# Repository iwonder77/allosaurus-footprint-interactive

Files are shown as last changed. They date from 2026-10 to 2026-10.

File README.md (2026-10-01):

# Allosaurus Footprint Stomp Pad Interactive

Three-channel, optically-isolated 24 V input board plus ESP32 show controller that turns industrial safety mats ("stomp pads") into clean, debounced triggers for synchronized video and LED strip output at the Need for Speed exhibit in Thanksgiving Point's Museum of Ancient Life. A visitor stomps a footprint mat, and the matching dinosaur's clip plays with an accompanying light strip animation around that Allosaurus' femur bone cast.

---

## At a Glance

| | |
| --- | --- |
| **Input domain** | 24 V DC current loop, one per mat (field wiring, up to ~10 ft) |
| **Logic domain** | 3.3 V, shared with the controller (no level shifting needed) |
| **Channels / mats** | 3 - `hatchling`, `juvenile`, `adult` (one per footprint mat) |
| **Input per channel** | ASOSafety safety mat (normally-open, passive dry contact) |
| **Isolation** | onsemi **H11L1M** optocoupler - one per channel |
| **Controller** | **ESP32-DevKitC** (`fqbn: esp32:esp32:esp32`) firmware sketch in `esp32/` |
| **Input logic** | Mat pressed → `Vo` LOW (**active-low**, external pull-up idles HIGH) |
| **Output banks** | Media (BrightSign) + LED Light Strip (controlled by QuinLED), both **active-low** 200 ms pulses |
| **Show rule** | First stomp wins; all mats locked out until that clip finishes |
| **PCB** | `2-layer, JLCPCB fab + assembly` |
| **Status** | PCB version June 2026 designed (see `ERRATA.md`) · firmware complete |

---

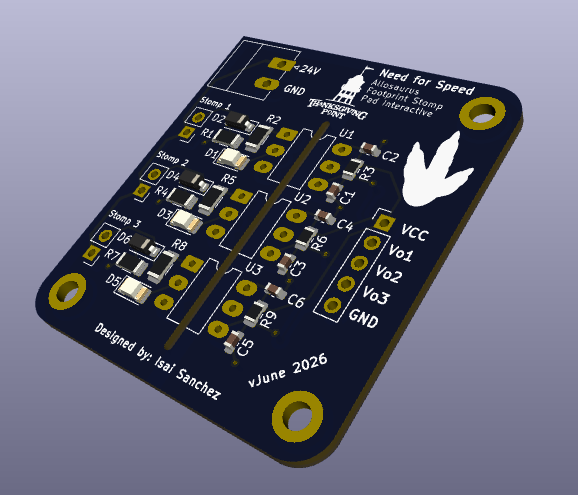
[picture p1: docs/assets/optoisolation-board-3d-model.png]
3D PCB Model


---

## Overview

The Allosaurus Footprint interactive lets visitors stomp on floor-mounted pads to trigger a short video, audio, and light response - a video clip on a BrightSign player and an LED-strip animation on a QuinLED driver - fired in sync from a single step. Each pad is an **industrial normally-open safety mat used here purely as a rugged foot switch** in order to run unattended 24/7 in an abusive museum exhibit environment.

The obvious approach is to wire each mat's dry contact straight into a GPIO with the internal pull-up and debounce in firmware. That may work on a bench, but is not the bullet proof solution on the floor for the following reasons:

- The mats sit **up to ~10 ft** from the controller.
- The exhibit must run **24/7, unattended, for years**, with **hundreds of activations a day** and cannot experience any brown-out or mat trigger failures.
- Hundreds of visitors means hundreds of potential **ESD events** onto the mat wiring.
- Industrial-rated mats need a "wetting" current to ensure reliable long-term operation of the dry contacts (part of the reason manufacturers specify connecting to a 24V system)

A bare high-impedance GPIO sense on a 10 ft run is an antenna prone to noise pickup and false triggers. The optoisolation board I designed was a cheap bulletproof add-on to solves both problems at the input stage, so the controller only ever sees a clean, isolated, logic-level edge - then the firmware does debounce, fault detection, and show sequencing on top.

---

# Hardware

## Hardware Design Requirements

The input board needed to:

- Convert a passive N.O. mat closure into a reliable 3.3 V logic trigger.
- Provide **galvanic isolation** between the 24 V field wiring and the 3.3 V logic, so ground offsets and transients on the mat side cannot reach the MCU.
- Resist false triggers from noise coupled onto the long mat cabling.
- Give maintenance staff a **visible per-channel indicator** to confirm at a glance that a mat is being pressed and its sense path is driven.
- Be manufacturable at JLCPCB (fab + assembly) with clean, auditable part placement and silkscreen labels.
- Run for years with essentially zero maintenance.

These led to a **24 V current loop driving an optocoupler per channel**: the current loop resists noise, adds a bit of "wetting" current, and the optocoupler provides isolation plus a clean Schmitt-trigger output edge for the show controller.

## Main Hardware Components

- onsemi **H11L1M** optocoupler - integrated **Schmitt-trigger, open-collector, logic-compatible** output
- **1N4148W** small-signal diode - reverse-polarity protection across the optocoupler input
- Visible indicator LED (green SMD) - per channel, on the input side
- Current-limiting resistors, pull-up resistors, decoupling/filter capacitors (see **Design Notes**)

The full BOM lives in `manufacturing/`.

## Full Schematic

Full schematic

## Main Hardware Architecture

The three channels are identical.

**Input side (referenced to `GND1`, the 24 V ground):**

```
+24V ── mat (N.O.) ── R_series ── [indicator LED] ── H11L1M IR LED ── GND1
                 └── D2 (1N4148W) across the LED string, reverse protection
```

While someone stands on the mat the contact closes and current flows, driving the H11L1M input IR LED and lighting the visible indicator - so the indicator doubles as direct confirmation the sense LED is driven.

> **Note:** rev 1 places the indicator LED _in series_ with the IR LED. This works but is being revised to a parallel branch - see **Hardware Revisions** and `ERRATA.md`.

**Output side (referenced to `GND2`, the 3.3 V ground):**

```
+3V3 ── R_pullup (2.2 kΩ) ──┬── Vo (H11L1M open-collector) ── ESP32 GPIO
                            └── C1 (0.1 µF) noise filter to GND2
+3V3 ── C2 (0.1 µF) decoupling, close to the H11L1M VCC pin ── GND2
```

The output is **active-low on a press**: pressed → IR LED on → output transistor on → `Vo` LOW. Idle → `Vo` pulled HIGH by the 2.2 kΩ. The output-side `VCC` shares the 3.3 V rail with the MCU so HIGH can never exceed the MCU input rail.

| Mat state | IR LED | `Vo` node | GPIO reads | Indicator LED |
| --- | --- | --- | --- | --- |
| Idle (open) | off | HIGH (~3.07 V) | HIGH | off |
| Pressed (closed) | on | LOW (≤ 0.4 V)  | LOW | lit |

## Design Notes

### Why a 24 V current loop instead of a bare GPIO

**Current loop, not voltage sense.** Pushing real current (target ~9–10 mA) through the H11L1M input LED is a low-impedance path; noise must overcome actual current to look like a valid change. Far harder to corrupt than a voltage on a high-impedance node over 10 ft.

**Wetting current (bonus).** Meaningful current through the dry mat contacts keeps a **wetting current** flowing, which helps those contacts resist any oxide film that makes aging switches flaky. This sets a _floor_ on the sense-branch current independent of the opto's switching threshold.

### Optocoupler output logic and levels

The H11L1M's integrated Schmitt trigger gives clean, bounce-free edges. Verified against the controller's input thresholds (ESP32 input thresholds are ratios of VDD):

| Parameter | Value | Source |
| --- | --- | --- |
| `V_IH(min)` ≈ 0.75·VDD | ~2.48 V | ESP32 datasheet |
| `V_IL(max)` ≈ 0.25·VDD | ~0.83 V | ESP32 datasheet |
| H11L1M `V_OL` | ≤ 0.4 V | datasheet (sinks 16 mA at 0.4 V max) |
| H11L1M output-off leakage `I_OH` | 100 µA  | datasheet |
| H11L1M `V_CC` range (min **3.0 V**) | 3–16 V  | datasheet |

With a **2.2 kΩ pull-up**: HIGH ≈ 3.3 − (~105 µA)(2.2 kΩ) ≈ **3.07 V** (~0.6 V over `V_IH`); LOW ≤ **0.4 V** (~0.4 V under `V_IL`); pressed-state sink ≈ 1.3 mA (far below 16 mA). The binding constraint is the HIGH side — the 100 µA leakage droops it — so the pull-up is kept small-ish. `C1` = 0.1 µF with the 2.2 kΩ gives RC ≈ **220 µs**: a **glitch filter, not a debouncer**. Mat bounce runs for milliseconds, so firmware debounce is still mandatory (and the firmware does far more than that - see below).

### Reverse-polarity protection

The 1N4148W spans the forward LED string, reverse-biased in normal use, conducting only on a reversed-polarity miswire. Confirm its orientation (cathode toward +24 V in normal operation). A single series Schottky on the 24 V input is the tidier belt-and-suspenders option if full reverse immunity is ever wanted.

## Hardware Revisions

Two changes are planned for the next board spin. **version June 2026 is functional as-is** - these are improvements, not blockers. Full detail, rationale, and selection guidance live in **[`ERRATA.md`](./ERRATA.md)** next to the rev-1 schematic/PCB files.

- **ERRATA-1: Indicator LED should be parallel, not series.** Version June 2026 shares one loop current between the IR LED and the indicator. Moving the indicator to its own parallel branch (each LED with its own resistor) lets each current be sized independently and stops an open-failed indicator from killing the sense path. **Recompute the opto current when you do**.
- **ERRATA-2: Add a TVS at each mat connector.** Given public foot traffic (ESD) over ~10 ft of exposed cable, 24/7 for years, a unidirectional TVS at each input protects the front-end. (It does _not_ protect the ESP32 - the opto already does that.) Recommended, not required.

## PCB & Manufacturing

**Isolation strategy (the whole point).** `GND1` (24 V) and `GND2` (3.3 V) are separate nets that **never** connect on the board - the only crossing is the opto's light barrier. Two separate bottom-layer copper pours with a ~3 mm gap, the barrier line running through each optocoupler, all three optos oriented identically.

**Mounting holes - verified safe.** The four corner holes carry **no copper** and take plastic standoffs for a custom 3D-printed mount, so hardware can't bridge `GND1` to `GND2`.

**Net classes**

| Class | Track width | Nets |
| --- | --- | --- |
| `Input_24V`  | 0.5 mm | `+24V`, `GND1` |
| `Output_3V3` | 0.3 mm | `+3V3`, `GND2`, `Vo` |

Both share via 0.6 mm / hole 0.3 mm (0.15 mm annular) and 0.3 mm clearance.

---

# Firmware

`esp32/` — a single non-blocking sketch that reads the three mats, validates each stomp, and fires the matching media + light triggers. No RTOS tasks, no delays; `loop()` runs the whole thing and feeds a hardware watchdog every pass.

## Pinout — `esp32/`

All constants live in `src/Config.h`. Index `i` ties together input `[i]`, media `[i]`, and light `[i]` (mat 1 = hatchling, 2 = juvenile, 3 = adult).

| GPIO | Direction | Connects to | Constant |
| --- | --- | --- | --- |
| 13 | Input (active-low)  | `Vo1` - hatchling opto output | `MAT_INPUT_PINS[0]` |
| 14 | Input (active-low)  | `Vo2` - juvenile opto output | `MAT_INPUT_PINS[1]` |
| 15 | Input (active-low)  | `Vo3` - adult opto output | `MAT_INPUT_PINS[2]` |
| 21 | Output (active-low) | BrightSign trigger - hatchling clip | `MEDIA_TRIGGER_PINS[0]` |
| 22 | Output (active-low) | BrightSign trigger - juvenile clip  | `MEDIA_TRIGGER_PINS[1]` |
| 23 | Output (active-low) | BrightSign trigger - adult clip | `MEDIA_TRIGGER_PINS[2]` |
| 16 | Output (active-low) | QuinLED trigger - hatchling strip | `LIGHT_TRIGGER_PINS[0]` |
| 17 | Output (active-low) | QuinLED trigger - juvenile strip | `LIGHT_TRIGGER_PINS[1]` |
| 18 | Output (active-low) | QuinLED trigger - adult strip | `LIGHT_TRIGGER_PINS[2]` |
| 25/26/27 | _reserved_ | former audio bank (WAV Trigger) | - (do not reuse) |

## Behavior

**Debounce / validation (per mat).** Three independent timing knobs in `Config.h`, each rejecting a different failure mode — deliberately not collapsed into one value:

| Knob | Default | Rejects |
| --- | --- | --- |
| `MAT_DEBOUNCE_MS` | 10 ms | fast edge chatter - line must be stable this long |
| `MAT_MIN_ON_MS` | 30 ms | short spikes - press must dwell this long to count (≥ debounce); also the event latency |
| `MAT_REARM_MS` | 80 ms | bouncy releases - line must read clear this long to re-arm |

**One video at a time (global lockout).** The first validated stomp wins: its clip is triggered and **every** mat input is ignored until that clip finishes, so a video always plays start-to-finish and is never cut off or re-triggered. Lockout = `VIDEO_LENGTH_MS[i]` (13 / 17 / 22 s) + `RETRIGGER_HEADROOM_MS` (1 s) → ~14 / 18 / 23 s. A stomp arriving during a lockout is **discarded**, not queued. This is a different mechanism from `MAT_REARM_MS` (a low-level per-mat cooldown).

**Fail-closed detection.** If a mat reads active continuously for `MAT_STUCK_MS` (10 s - far longer than any real stomp: a welded contact, a stuck mat, or a shorted line), that mat is flagged **faulted**: it stops emitting events and its outputs are forced idle so a stuck input can't leave a device asserted. It auto-recovers after the line reads clear for `MAT_FAULT_RECOVER_MS` (500 ms), re-arming through the boot-safe path.

**Boot-safe.** Each detector starts in `WaitForRelease`, so a mat already held down at power-on never produces a spurious event - it arms only after a confirmed clean release.

**Watchdog.** `loop()` is fully non-blocking and feeds the task watchdog (TWDT) every pass. If anything ever wedges the main task past `WDT_TIMEOUT_MS` (5 s), the watchdog panics and resets the board - the exhibit self-recovers instead of hanging.

## Architecture

The `.ino` handles bring-up (pin setup, watchdog subscribe) and the per-mat loop; the real press logic lives in `src/`.

- **`MatInput`**: a non-blocking, debounced press detector for one active-low opto input, owning only its own state machine (no dependency on Serial or the outputs). `update()` advances it, `eventFired()` latches true exactly once per validated stomp (reading clears it), `pressed()` / `faulted()` / `rawActive()` expose state. The FSM: `WaitForRelease → Armed → PressDebounce → PressConfirm → Held`, with `Faulted` entered from anywhere on a stuck line. Fault and min-on timing are measured against `millis()` marks, so nothing blocks.
- **Main sketch (`esp32.ino`)**: owns one `MatInput` per mat and two output banks (`BANK_MEDIA`, `BANK_LIGHT`) in an index-aligned table, so `triggerMat(i)` fires both of mat `i`'s lines at once and `serviceOutputs()` returns each to idle after the pulse width — non-blocking, so mat scanning never stalls behind an in-flight pulse. It owns the global lockout, logs faults/recoveries once on their edge, and forces a faulted mat's outputs idle. The lockout comparison is rollover-safe (`(int32_t)(now - lockoutUntil) >= 0`).
- **`Config.h`**: single source of truth for pins, polarity, and all timing. `constexpr` throughout (compile-time, zero RAM). Everything you'd tune on the bench lives here so the logic modules stay untouched.

## Deployment & Bring-up

### Flashing

Platform is set in `sketch.yaml` (`esp32:esp32:esp32`). `default_port` is committed as `/dev/cu.usbserial-0001` - **change it to your machine's serial port**, or pass `-p <port>` on upload. A plain `arduino-cli compile` / `upload` builds and flashes the sketch.

### Tuning on the real mat

Leave `SERIAL_LOG_EVENTS = true` and watch the serial console at **115200**. Then:

- **Double-triggers on one stomp** → increase `MAT_DEBOUNCE_MS` (and/or `MAT_REARM_MS`).
- **Missed / dropped stomps** → decrease `MAT_MIN_ON_MS` (keep it ≥ `MAT_DEBOUNCE_MS`).
- Set `VIDEO_LENGTH_MS[]` to the **real** clip durations per mat - these drive the lockout, so a value shorter than the clip will let the exhibit re-arm mid-video.

### What working looks like

| Event | Serial line |
| --- | --- |
| Boot | `Allosaurus Footprint Interactive - ready` |
| Valid stomp | `Mat N triggered (input GPIO .. -> media .. / light ..); ignoring all mats for .. ms` |
| Stuck mat / short | `FAULT: Mat N stuck active (input GPIO ..) - check for a failed-closed mat/short` |
| Fault clears | `RECOVERED: Mat N back to normal (input GPIO ..)` |

### When something is wrong

| Symptom | Likely cause | Check |
| --- | --- | --- |
| A mat never triggers | Input wiring / opto / that mat | Does the on-board indicator LED light on press? Is `Vo` reaching the right GPIO? |
| A stomp fires media but not lights (or vice-versa) | One output bank's wire | That mat's `MEDIA`/`LIGHT` GPIO to the device input, plus common ground |
| Downstream device never reacts to a pulse | Polarity / reference mismatch | Device must trigger on an **active-LOW** pulse and share ground; input must be 3.3 V |
| `FAULT: Mat N stuck active` on repeat | Welded contact, stuck mat, or shorted run | Inspect that mat and its cable; fault clears itself once the line reads clear |
| Exhibit ignores stomps for ~15–25 s | **Not a fault** — global lockout | A clip is playing; by design all mats are ignored until it ends |
| Board reboots every few seconds | Watchdog fired — `loop()` stalled | Something is blocking the main task; check recent changes / peripherals |

### Quirks worth knowing

- **Simultaneous stomps: first wins.** If two mats are hit close together, only the first registers; the rest are ignored (not queued) until the clip finishes. Intended - one video at a time.
- **A stomp during a video does nothing.** Discarded, not buffered, so the exhibit never "fires late" when the lockout ends.
- **Audio is not wired.** An audio bank (SparkFun + Robertsonics WAV Trigger) was prototyped and removed; GPIO 25/26/27 are reserved. To restore it, re-add `AUDIO_TRIGGER_PINS[] = {25, 26, 27}`, its `static_assert`, and a `BANK_AUDIO` entry in `OUTPUT_BANK_PINS`.

---

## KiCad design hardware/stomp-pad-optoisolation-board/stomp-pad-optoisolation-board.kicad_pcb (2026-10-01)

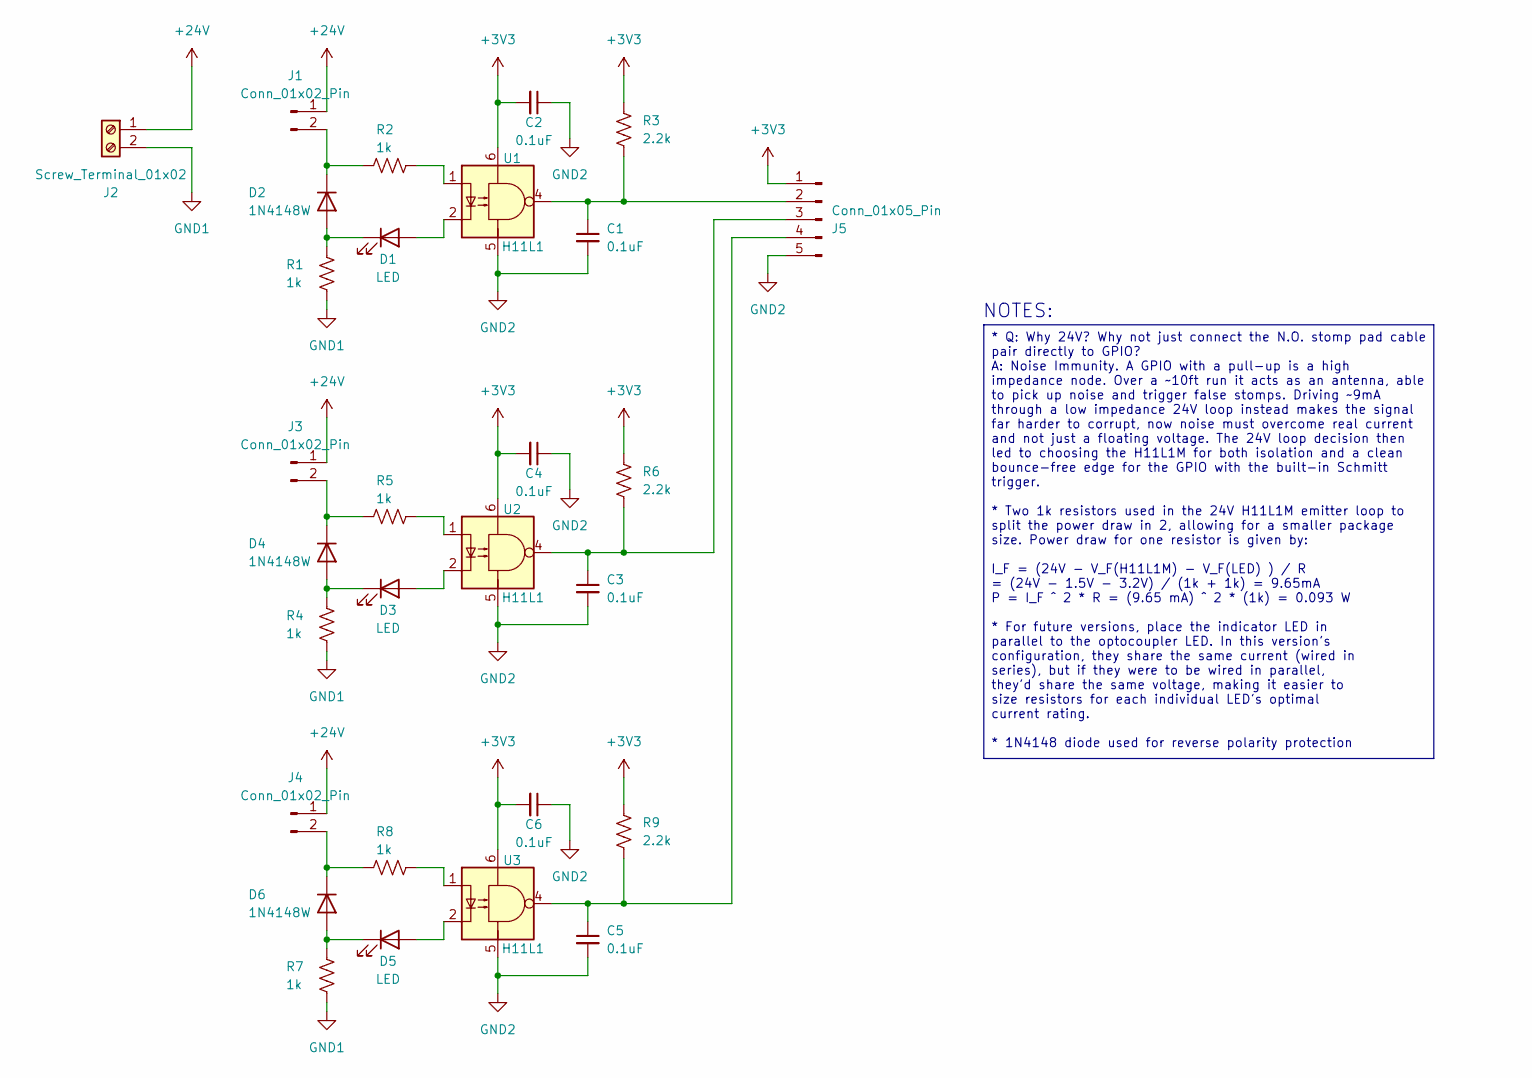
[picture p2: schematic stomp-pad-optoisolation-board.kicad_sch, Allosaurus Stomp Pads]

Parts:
C1, C2, C3, C4, C5, C6: 0.1uF; C_0603_1608Metric
D1, D3, D5: LED; LED_1206_3216Metric
D2, D4, D6: 1N4148W; D_SOD-123
J1, J3, J4: Conn_01x02_Pin; PinHeader_1x02_P2.54mm_Vertical
J2: Screw_Terminal_01x02; PhoenixContact_MC_1,5_2-G-3.5_1x02_P3.50mm_Horizontal
J5: Conn_01x05_Pin; PinHeader_1x05_P2.54mm_Vertical
R1, R2, R4, R5, R7, R8: 1k; R_1206_3216Metric
R3, R6, R9: 2.2k; R_0805_2012Metric
U1, U2, U3: H11L1; DIP-6_W7.62mm_LongPads

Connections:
+3V3: C2.2, C4.2, C6.2, J5.1, R3.1, R6.1, R9.1, U1.6, U2.6, U3.6
+24V: J1.1, J2.1, J3.1, J4.1
GND1: J2.2, R1.1, R4.1, R7.1
GND2: C1.2, C2.1, C3.2, C4.1, C5.2, C6.1, J5.5, U1.5, U2.5, U3.5
unnamed: D1.2 (A), U1.2
unnamed: D1.1 (K), D2.2 (A), R1.2
unnamed: D2.1 (K), J1.2, R2.1
unnamed: D3.2 (A), U2.2
unnamed: D3.1 (K), D4.2 (A), R4.2
unnamed: D4.1 (K), J3.2, R5.1
unnamed: D5.2 (A), U3.2
unnamed: D5.1 (K), D6.2 (A), R7.2
unnamed: D6.1 (K), J4.2, R8.1
unnamed: C1.1, J5.2, R3.2, U1.4
unnamed: C3.1, J5.3, R6.2, U2.4
unnamed: C5.1, J5.4, R9.2, U3.4
unnamed: R2.2, U1.1
unnamed: R5.2, U2.1
unnamed: R8.2, U3.1

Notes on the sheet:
NOTES:
* Q: Why 24V? Why not just connect the N.O. stomp pad cable pair directly to GPIO? A: Noise Immunity. A GPIO with a pull-up is a high impedance node. Over a ~10ft run it acts as an antenna, able to pick up noise and trigger false stomps. Driving ~9mA through a low impedance 24V loop instead makes t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

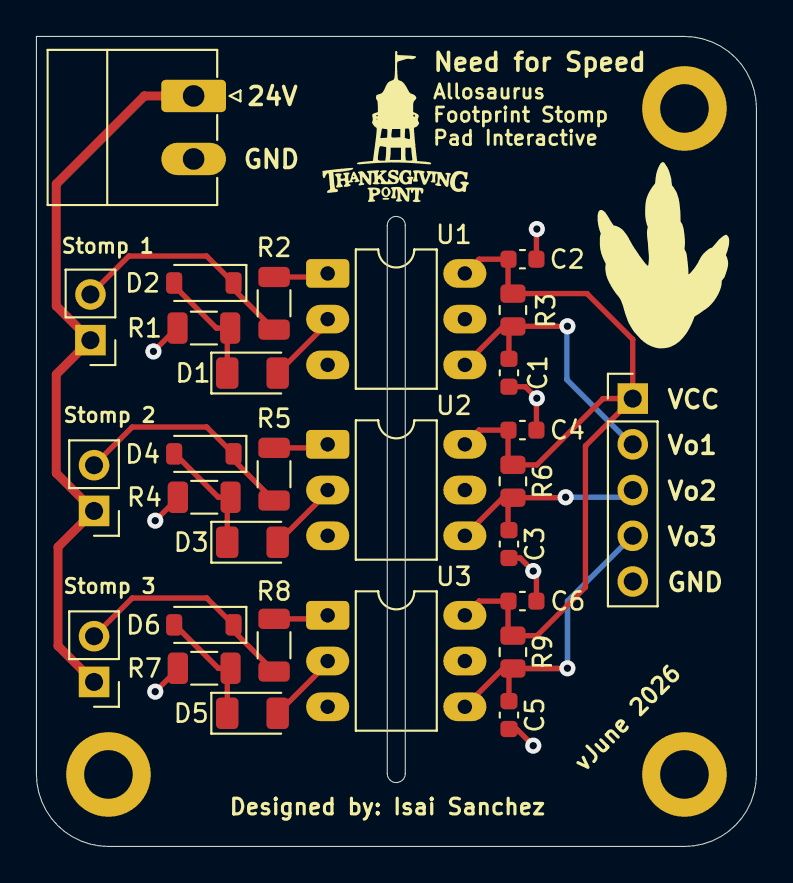
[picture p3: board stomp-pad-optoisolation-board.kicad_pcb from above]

Board: 2 copper layers, 40.0 x 45.0 mm, 29 parts (0 on the bottom side), 19 nets.

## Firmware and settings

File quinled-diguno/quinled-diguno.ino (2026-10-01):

/**
 * Allosaurus Footprint Interactive — LED strip controller
 * File: quinled-diguno.ino
 * Board: QuinLED Dig-Uno (ESP32-based; LED outputs are level-shifted to 5V)
 * Strip: WS2815 addressable, 152 pixels
 *
 * Behaviour:
 *   - IDLE: the whole strip holds a constant warm white / amber glow.
 *   - On a stomp (GPIO15 pulled LOW by the optocoupler mat-trigger board) a fast
 *     red "snake" wipes down the strip: a leading pixel advances and every pixel
 *     it passes stays red, overtaking the amber glow. When the head reaches the
 *     final pixel the strip holds full red for FULL_RED_HOLD_MS (ignoring any
 *     further stomps), then cross-fades smoothly back to the amber idle glow.
 *
 * The GPIO15 input is debounced with the same active-low state machine used by
 * the esp32 mat sketch (debounce window + minimum on-time + re-arm cooldown,
 * plus boot-safety), so contact/optocoupler chatter can't double-fire.
 *
 * PER-BOARD BUILD: each QuinLED board accompanies one mat's video, and its
 * animation cycle equals that video's length, selected at COMPILE TIME with
 * -DBOARD_ID=n (see the "Per-board video length" section below).
 */

#include <FastLED.h>

// ===================== LED strip ==========================================
constexpr uint16_t NUM_LEDS = 152;
constexpr uint8_t LED_DATA_PIN = 3;  // QuinLED Dig-Uno LED data output
#define LED_TYPE WS2815
#define COLOR_ORDER GRB
constexpr uint8_t BRIGHTNESS_PCT = 75;  // master brightness, percent

// Idle glow and snake colors. IDLE_COLOR is a warm, slightly-amber white; tune
// the green/blue channels down for more amber, up for cooler white.
const CRGB IDLE_COLOR = CRGB(255, 120, 40);
const CRGB SNAKE_COLOR = CRGB::Red;

// ===================== Snake animation ====================================

constexpr float SNAKE_SPEED_PPS = 100.0f;  // leading-pixel speed, pixels/sec (higher = faster)
constexpr uint8_t TARGET_FPS = 120;        // render cap

// ===================== Per-board video length (compile-time) =============
/*
 * This board's animation runs for exactly one video length: the snake wipe, the
 * full-red hold, and the closing fade back to idle. The hold is whatever time
 * is left after the wipe and fade, so wipe + hold + fade always sums to
 * TOTAL_CYCLE_MS (see the derivation below) — raise SNAKE_SPEED_PPS and the hold
 * grows, lower it and the hold shrinks. Stomps on MAT_INPUT_PIN are ignored for
 * the whole cycle.
 *
 * Each QuinLED board accompanies one mat's video, so TOTAL_CYCLE_MS is that
 * video's length, chosen at COMPILE TIME. All three lengths live in the array
 * below (index-matched to the mats, mirroring VIDEO_LENGTH_MS[] in the esp32
 * sketch); BOARD_ID picks which one THIS board uses:
 *
 *   arduino-cli compile --build-property \
 *     compiler.cpp.extra_flags=-DBOARD_ID=2 --fqbn esp32:esp32:esp32 quinled-diguno
 *
 * A plain build with no -DBOARD_ID defaults to mat 1, so it still compiles/runs.
 */
#ifndef BOARD_ID
#define BOARD_ID 3
#endif

constexpr uint32_t VIDEO_LENGTHS_MS[] = {
  12000,  // hatchling footprint mat clip length
  16000,  // juvenile footprint mat clip length
  21000,  // adult footprint mat clip length
};
static_assert(BOARD_ID >= 1 && BOARD_ID <= (int)(sizeof(VIDEO_LENGTHS_MS) / sizeof(VIDEO_LENGTHS_MS[0])),
              "BOARD_ID must be 1..3; set it with -DBOARD_ID=n at compile time");

// This board's animation cycle == its video length.
constexpr uint32_t TOTAL_CYCLE_MS = VIDEO_LENGTHS_MS[BOARD_ID - 1];

// Smooth cross-fade from full red back to the amber idle glow at the end of the
// cycle. This is carved out of TOTAL_CYCLE_MS, not added on top.
constexpr uint32_t FADE_TO_IDLE_MS = 1000;

// Nominal time for the head to travel the strip (head goes from pixel 0 to
// NUM_LEDS-1 at SNAKE_SPEED_PPS); the rest of the budget is the full-red hold.
constexpr uint32_t SNAKE_WIPE_MS =
  (uint32_t)((NUM_LEDS - 1) / SNAKE_SPEED_PPS * 1000.0f);
static_assert(SNAKE_WIPE_MS + FADE_TO_IDLE_MS <= TOTAL_CYCLE_MS,
              "Snake wipe + fade exceed TOTAL_CYCLE_MS; raise the total or speed");
constexpr uint32_t FULL_RED_HOLD_MS =
  TOTAL_CYCLE_MS - SNAKE_WIPE_MS - FADE_TO_IDLE_MS;

constexpr uint16_t FRAME_INTERVAL_MS = 1000 / TARGET_FPS;

// ===================== Mat trigger input (optocoupler) ====================
// GPIO15 idles HIGH (external pull-up on the opto board) and is pulled LOW when
// the mat is stomped. GPIO15 is an ESP32 strapping pin that must be HIGH at
// boot — idle-HIGH satisfies that, so this wiring is boot-safe.
#define MAT_INPUT_PIN 32
constexpr bool MAT_ACTIVE_LOW = true;
constexpr bool MAT_USE_INTERNAL_PULLUP = true;  // `false` if external pull-up present

// Three independent debounce knobs (see the esp32 sketch's Config.h for the
// rationale of each). MAT_MIN_ON_MS must be >= MAT_DEBOUNCE_MS.
constexpr uint16_t MAT_DEBOUNCE_MS = 10;  // edge stability window
constexpr uint16_t MAT_MIN_ON_MS = 30;    // min dwell to count
constexpr uint16_t MAT_REARM_MS = 1000;   // min off-time before re-arming

/*
 * MatTrigger — non-blocking, debounced press detector for one active-low input.
 * Fires eventFired() exactly once per validated stomp. begin() starts in
 * WaitForRelease so a mat held at power-on never produces a spurious trigger.
 */
class MatTrigger {
public:
  void begin(uint8_t pin) {
    pin_ = pin;
    pinMode(pin_, MAT_USE_INTERNAL_PULLUP ? INPUT_PULLUP : INPUT);
    state_ = WaitForRelease;
    event_ = false;
    t_mark_ = millis();
  }

  // Advance the state machine. Non-blocking; call every loop.
  void update() {
    const uint32_t now = millis();
    const bool active = rawActive();

    switch (state_) {
      case WaitForRelease:  // boot-safe entry + cooldown; needs continuous release
        if (active) {
          t_mark_ = now;
        } else if (now - t_mark_ >= MAT_REARM_MS) {
          state_ = Armed;
        }
        break;

      case Armed:
        if (active) {  // first active edge
          t_mark_ = now;
          state_ = PressDebounce;
        }
        break;

      case PressDebounce:
        if (!active) {
          state_ = Armed;  // dropped during debounce -> chatter
        } else if (now - t_mark_ >= MAT_DEBOUNCE_MS) {
          state_ = PressConfirm;
        }
        break;

      case PressConfirm:  // min-on measured from the first edge
        if (!active) {
          t_mark_ = now;
          state_ = WaitForRelease;  // released too soon -> too short
        } else if (now - t_mark_ >= MAT_MIN_ON_MS) {
          event_ = true;  // VALIDATED STOMP — latch the event
          state_ = Held;
        }
        break;

      case Held:
        if (!active) {
          t_mark_ = now;  // begin cooldown
          state_ = WaitForRelease;
        }
        break;
    }
  }

  // True exactly once per validated stomp; reading it clears the latch.
  bool eventFired() {
    if (event_) {
      event_ = false;
      return true;
    }
    return false;
  }

private:
  bool rawActive() const {
    const int level = digitalRead(pin_);
    return MAT_ACTIVE_LOW ? (level == LOW) : (level == HIGH);
  }

  enum State : uint8_t { WaitForRelease,
                         Armed,
                         PressDebounce,
                         PressConfirm,
                         Held };

  uint8_t pin_ = 0;
  State state_ = WaitForRelease;
  bool event_ = false;
  uint32_t t_mark_ = 0;
};

// ===================== Runtime state ======================================
CRGB leds[NUM_LEDS];
MatTrigger mat;

enum Mode : uint8_t { IDLE,
                      SNAKE,
                      SNAKE_HOLD,
                      FADE_TO_IDLE };
Mode mode = IDLE;

float snakeHead = 0.0f;    // leading-pixel position, fractional
uint32_t lastFrameMs = 0;  // last rendered frame timestamp
uint32_t holdStart = 0;    // full-red dwell start timestamp
uint32_t fadeStart = 0;    // fade-to-idle start timestamp

// Paint the whole strip with the amber idle glow.
void renderIdle() {
  fill_solid(leds, NUM_LEDS, IDLE_COLOR);
  FastLED.show();
}

// Begin the red snake wipe from the first pixel.
void startSnake(uint32_t now) {
  mode = SNAKE;
  snakeHead = 0.0f;
  lastFrameMs = now;
}

// Advance and draw one snake frame: pixels at/behind the head are red, pixels
// ahead of it keep the amber idle glow. Transitions to SNAKE_HOLD at the end.
void updateSnake(uint32_t now) {
  const uint32_t dtMs = now - lastFrameMs;
  if (dtMs < FRAME_INTERVAL_MS) return;
  lastFrameMs = now;

  snakeHead += SNAKE_SPEED_PPS * (dtMs / 1000.0f);

  int head = (int)snakeHead;
  bool reachedEnd = false;
  if (head >= NUM_LEDS - 1) {
    head = NUM_LEDS - 1;
    reachedEnd = true;
  }

  for (int i = 0; i < NUM_LEDS; ++i) {
    leds[i] = (i <= head) ? SNAKE_COLOR : IDLE_COLOR;
  }
  FastLED.show();

  if (reachedEnd) {
    mode = SNAKE_HOLD;
    holdStart = now;
  }
}

// Cross-fade the whole strip from full red back to the amber idle glow over
// FADE_TO_IDLE_MS, then settle into IDLE. The strip is uniform here, so one
// blended color fills every pixel.
void updateFade(uint32_t now) {
  const uint32_t dtMs = now - lastFrameMs;
  if (dtMs < FRAME_INTERVAL_MS) return;
  lastFrameMs = now;

  const uint32_t elapsed = now - fadeStart;
  if (elapsed >= FADE_TO_IDLE_MS) {
    mode = IDLE;
    renderIdle();
    return;
  }

  // 0 -> full red, 255 -> full idle color.
  const uint8_t amount = (uint8_t)(elapsed * 255UL / FADE_TO_IDLE_MS);
  fill_solid(leds, NUM_LEDS, blend(SNAKE_COLOR, IDLE_COLOR, amount));
  FastLED.show();
}

void setup() {
  FastLED.addLeds<LED_TYPE, LED_DATA_PIN, COLOR_ORDER>(leds, NUM_LEDS);
  FastLED.setBrightness((255 * BRIGHTNESS_PCT) / 100);

  mat.begin(MAT_INPUT_PIN);

  renderIdle();
}

void loop() {
  const uint32_t now = millis();

  mat.update();
  const bool stomped = mat.eventFired();

  switch (mode) {
    case IDLE:
      if (stomped) startSnake(now);  // stomps during animation are ignored
      break;

    case SNAKE:
      updateSnake(now);
      break;

    case SNAKE_HOLD:
      // Full-red hold: `stomped` is still consumed above but deliberately
      // ignored here, so no input can retrigger until the timer elapses.
      if (now - holdStart >= FULL_RED_HOLD_MS) {
        mode = FADE_TO_IDLE;
        fadeStart = now;
        lastFrameMs = now;
      }
      break;

    case FADE_TO_IDLE:
      // Smooth return to idle; stomps remain ignored until the fade completes.
      updateFade(now);
      break;
  }
}

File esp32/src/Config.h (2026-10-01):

#pragma once
#include <Arduino.h>

/*
 * Config.h — single source of truth for pins, polarity, and timing.
 *
 * Everything you might change on the bench lives here so the logic modules
 * (MatInput) stay untouched. Constants are `constexpr` (compile-time, zero
 * RAM).
 *
 * Target board: ESP32 (see sketch.yaml -> esp32:esp32:esp32).
 */

// ===================== Mat triggers (optocoupler inputs) ==================
/*
 * Each mat is a dry, normally-open contact switch on a long wire run, isolated
 * by an H11L1M. The optocoupler output is open-collector with an EXTERNAL
 * pull-up to 3.3V, so:  idle (unpressed) = HIGH, stomped = LOW  => active-low.
 *
 * Index order defines the mat numbering used everywhere else: MAT_INPUT_PINS[i]
 * is answered by MEDIA_TRIGGER_PINS[i] (same index).
 */
constexpr uint8_t MAT_INPUT_PINS[] = {
    13, // hatchling
    14, // juvenile
    15  // adult
};
constexpr uint8_t MAT_COUNT =
    sizeof(MAT_INPUT_PINS) / sizeof(MAT_INPUT_PINS[0]);

// pressed = LOW because the external pull-up idles the line HIGH.
constexpr bool MAT_ACTIVE_LOW = true;

// The isolation stage already provides an external pull-up, so we use a plain
// INPUT. Set true only as a failsafe if you suspect the external pull-up; the
// internal ~45k in parallel is harmless but shifts the idle threshold slightly.
constexpr bool MAT_ENABLE_INTERNAL_PULLUP = false;

/*
 * Three INDEPENDENT timing knobs. They are intentionally NOT collapsed into one
 * value — each rejects a different failure mode. Defaults are sane starting
 * points; tune on the real mat with SERIAL_LOG_EVENTS on (double-triggers =
 * increase, missed stomps = decrease).
 *
 *   MAT_DEBOUNCE_MS : the input must stay continuously active for this long
 *                     before we BELIEVE the press began. Rejects fast edge
 *                     chatter from the contact/optocoupler. Sets when pressed()
 *                     flips true.
 *
 *   MAT_MIN_ON_MS   : the press must remain active at least this long (measured
 *                     from the first edge) before it COUNTS as one event.
 *                     Rejects short spikes that survive debounce. This is also
 *                     the event latency — set it small for snappy triggering.
 *                     MUST BE >= MAT_DEBOUNCE_MS.
 *
 *   MAT_REARM_MS    : after release, the input must read inactive continuously
 *                     for this long before the NEXT press can register. This is
 *                     the cooldown that prevents a single bouncy release from
 *                     re-triggering, and it also gates boot-while-pressed.
 */
constexpr uint16_t MAT_DEBOUNCE_MS = 10; // edge stability window
constexpr uint16_t MAT_MIN_ON_MS = 30;   // min dwell to count (>= debounce)
constexpr uint16_t MAT_REARM_MS = 80;    // min off-time before re-arming

// ===================== Fault detection (fail-closed) ======================
/*
 * A mat "fails closed" when its contact welds shut, the mat is physically stuck
 * down, or the long wire run shorts: the optocoupler output is then held LOW
 * (active) indefinitely. No real stomp lasts anywhere near this long, so if a
 * mat's input stays CONTINUOUSLY active for MAT_STUCK_MS we flag it FAULTED —
 * the detector stops emitting stomp events for that mat and the sketch forces
 * its media output back to idle and logs the fault.
 *
 * The mat auto-recovers once its line reads inactive (HIGH) continuously for
 * MAT_FAULT_RECOVER_MS, at which point it re-arms through the normal boot-safe
 * WaitForRelease path.
 *
 * MAT_STUCK_MS must be comfortably longer than the longest legitimate stomp.
 */
constexpr uint32_t MAT_STUCK_MS = 10000;       // continuous-active -> fault
constexpr uint32_t MAT_FAULT_RECOVER_MS = 500; // continuous-clear -> recovered

// ===================== Downstream trigger outputs =========================
/*
 * Each validated stomp fires the output banks simultaneously, one output per
 * mat in each bank: media (BrightSign) and light strip. Every bank behaves
 * identically — the line idles HIGH and is pulsed LOW for OUTPUT_PULSE_MS,
 * because the downstream devices trigger on a LOW input.
 *
 * Within every bank, index i is driven by MAT_INPUT_PINS[i] (same index), so
 * mat 1 -> {MEDIA[0], LIGHT[0]}, and so on.
 *
 * Wiring: each ESP32 GPIO -> the downstream device's GPIO input, plus a COMMON
 * GROUND to every device. ESP32 outputs are 3.3V logic; confirm each input is
 * 3.3V-referenced before connecting.
 *
 * AUDIO: an audio bank was added at first to test a polyphonic audio module
 * (sparkfun + robertsonic's WAV trigger) but has since been removed
 * GPIO25/26/27 are left reserved for it — do not reuse them. To bring audio
 * back, re-add AUDIO_TRIGGER_PINS[] = {25, 26, 27} plus its static_assert and
 * a BANK_AUDIO entry in the sketch's OUTPUT_BANK_PINS table.
 */
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

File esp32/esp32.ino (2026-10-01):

/**
* Interactive: Allosaurus Footprint Interactive
* File: esp32.ino
*
* Description: 
* Main ESP32 firmware that reads three stomp-pad mats (industrial 
* pressure safety mats) through H11L1M optoisolators and, on a validated stomp,
* pulses two GPIOs LOW at once to trigger the matching mat's media (BrightSign)
* and QuinLED light strip driver
*
*
* Author: Isai Sanchez  
* Date: 7-31-2026
* Board: ESP32-DevKitC
* Notes:
*   - One video plays at a time: the FIRST stomp wins, and every mat input is then
*   ignored until that mat's video finishes (see Config.h), so a clip is never in
*   danger of being cut off or re-triggered mid-play.
*
*   - Signal chain per mat:
*     dry N.O. contact --> long wire run --> H11L1M optoisolator --> ESP32 input
*     The optocoupler output is open-collector with an external pull-up:
*       idle (unpressed) = HIGH
*       stomped = LOW  (active-low).
*     (see optocoupler schematic for reasoning behind its implementation)
*
* (c) Thanksgiving Point Exhibits Electronics Team — 2025
*/

#include "esp_task_wdt.h"

#include "src/Config.h"
#include "src/MatInput.h"

// One detector per mat. Index i drives index i of every output bank below.
static MatInput mats[MAT_COUNT];

// The output banks that fire together on each validated stomp. Within every
// bank, index i corresponds to MAT_INPUT_PINS[i]. (A BANK_AUDIO entry was
// removed at the design team's request; see Config.h for how to restore it.)
enum OutputBankId : uint8_t { BANK_MEDIA,
                              BANK_LIGHT,
                              BANK_COUNT };

static const uint8_t *const OUTPUT_BANK_PINS[BANK_COUNT] = {
  MEDIA_TRIGGER_PINS,
  LIGHT_TRIGGER_PINS,
};

// Non-blocking pulse bookkeeping per (bank, mat): while active, the line is held
// at its trigger level until OUTPUT_PULSE_MS has elapsed since pulseStart.
static bool pulseActive[BANK_COUNT][MAT_COUNT] = {};
static uint32_t pulseStart[BANK_COUNT][MAT_COUNT] = {};

// Latched fault state per mat, so we log each fail-closed / recovery once (on
// the edge) rather than every loop.
static bool matFaulted[MAT_COUNT] = { false };

// Global retrigger lockout. After a mat fires, EVERY mat input is ignored until
// this deadline (that mat's video length + RETRIGGER_HEADROOM_MS), so a video
// always plays start-to-finish. lockoutActive gates the comparison so a plain
// millis() rollover can't look like an expired lockout.
static bool lockoutActive = false;
static uint32_t lockoutUntil = 0;

// Logic levels for any trigger line, derived from its active polarity (shared
// by all banks).
static inline uint8_t triggerIdleLevel() {
  return OUTPUT_TRIGGER_ACTIVE_LOW ? HIGH : LOW;
}
static inline uint8_t triggerActiveLevel() {
  return OUTPUT_TRIGGER_ACTIVE_LOW ? LOW : HIGH;
}

// Fire every bank's output for mat i at once (media + light). Each line is
// driven active; serviceOutputs() returns them to idle after OUTPUT_PULSE_MS.
static void triggerMat(uint8_t i, uint32_t now) {
  for (uint8_t b = 0; b < BANK_COUNT; ++b) {
    digitalWrite(OUTPUT_BANK_PINS[b][i], triggerActiveLevel());
    pulseActive[b][i] = true;
    pulseStart[b][i] = now;
  }
}

// Return any output line to idle once its pulse width has elapsed. Non-blocking
// so mat scanning is never stalled by an in-flight pulse.
static void serviceOutputs(uint32_t now) {
  for (uint8_t b = 0; b < BANK_COUNT; ++b) {
    for (uint8_t i = 0; i < MAT_COUNT; ++i) {
      if (pulseActive[b][i] && (now - pulseStart[b][i]) >= OUTPUT_PULSE_MS) {
        digitalWrite(OUTPUT_BANK_PINS[b][i], triggerIdleLevel());
        pulseActive[b][i] = false;
      }
    }
  }
}

// Immediately force all of mat i's output lines idle and cancel any in-flight
// pulses. Used when a mat faults so a stuck input can't leave outputs asserted.
static void forceMatIdle(uint8_t i) {
  for (uint8_t b = 0; b < BANK_COUNT; ++b) {
    digitalWrite(OUTPUT_BANK_PINS[b][i], triggerIdleLevel());
    pulseActive[b][i] = false;
  }
}

// Subscribe the main (loop) task to the hardware task watchdog. Handles both
// the ESP32 Arduino core 3.x config-struct API and the 2.x timeout/panic API.
static void watchdogBegin() {
#if ESP_ARDUINO_VERSION_MAJOR >= 3
  const esp_task_wdt_config_t wdtConfig = {
    .timeout_ms = WDT_TIMEOUT_MS,
    .idle_core_mask = 0,    // don't watch the idle tasks, only ours
    .trigger_panic = true,  // panic + reset on timeout
  };
  esp_task_wdt_deinit();  // the core may have already initialised the TWDT
  esp_task_wdt_init(&wdtConfig);
#else
  esp_task_wdt_init(WDT_TIMEOUT_MS / 1000, true);
#endif
  esp_task_wdt_add(NULL);  // NULL = the currently running (loop) task
}

void setup() {
  Serial.begin(SERIAL_BAUD);

  for (uint8_t i = 0; i < MAT_COUNT; ++i) {
    mats[i].begin(MAT_INPUT_PINS[i]);
  }

  for (uint8_t b = 0; b < BANK_COUNT; ++b) {
    for (uint8_t i = 0; i < MAT_COUNT; ++i) {
      pinMode(OUTPUT_BANK_PINS[b][i], OUTPUT);
      digitalWrite(OUTPUT_BANK_PINS[b][i], triggerIdleLevel());
    }
  }

  watchdogBegin();

  Serial.println(F("Allosaurus Footprint Interactive - ready"));
}
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

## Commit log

2026-07-15 attached esp32 port and fqbn to this sketch
2026-07-15 swap in mat trigger classes and config file from previous project
    [Config.h, MatInput.h]
2026-07-22 add diguno code for LED perimeter strip animation for the bone box
2026-10-01 feat: ignoring KiCad files
    [stomp-pad-optoisolation-board.kicad_pcb, stomp-pad-optoisolation-board.kicad_sch]
